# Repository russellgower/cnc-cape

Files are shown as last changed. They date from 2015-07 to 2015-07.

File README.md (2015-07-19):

CNC Cape for the Beaglebone Black.

<br />This work is licensed under a <a rel="license" href="http://creativecommons.org/licenses/by-sa/4.0/">Creative Commons Attribution-ShareAlike 4.0 International License</a>.

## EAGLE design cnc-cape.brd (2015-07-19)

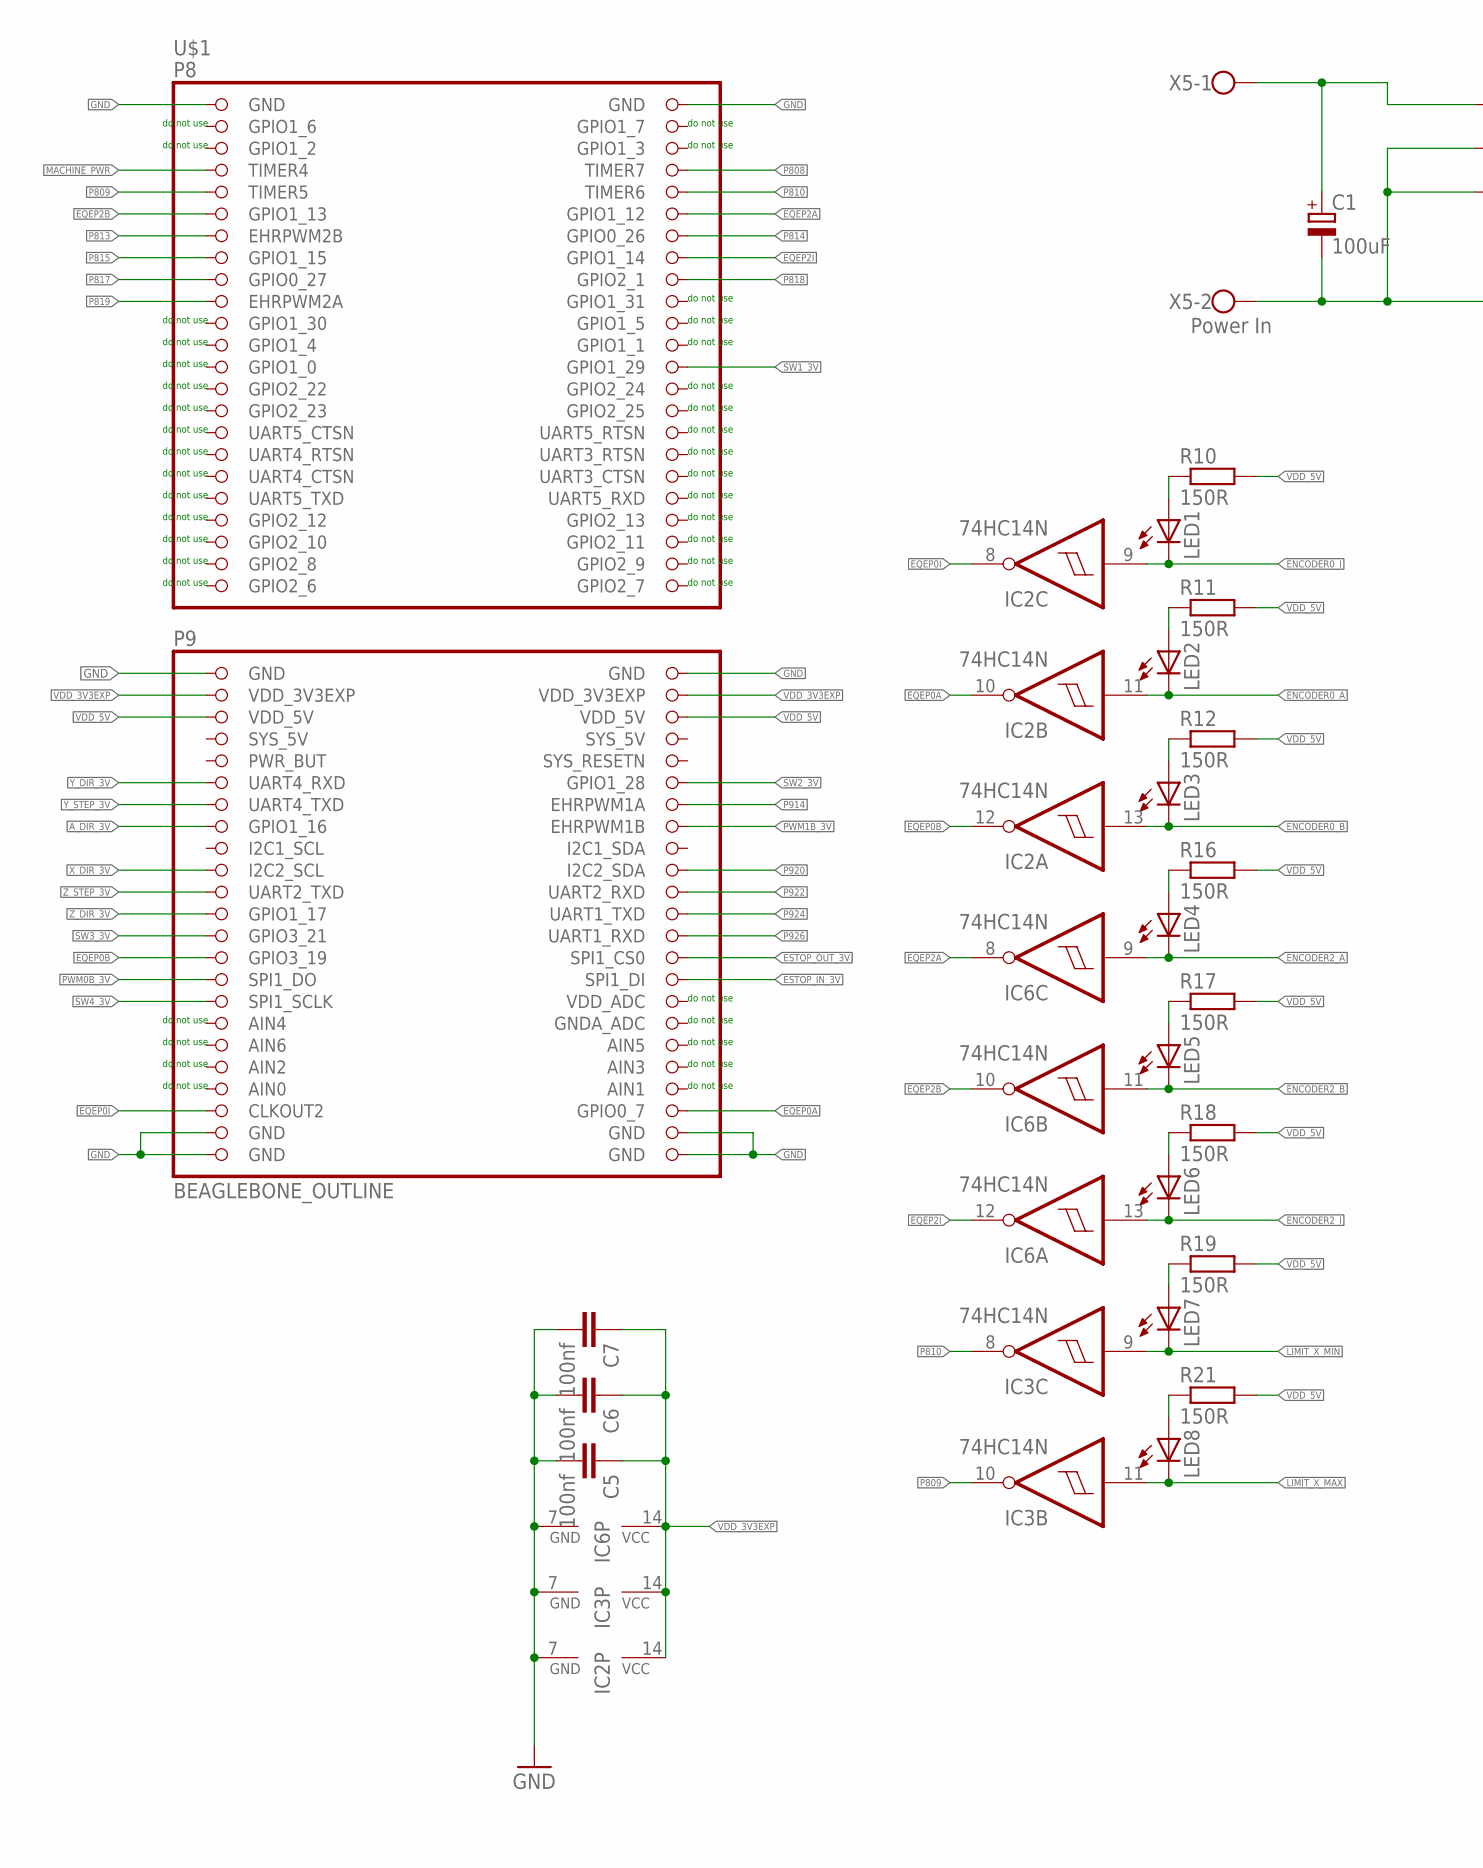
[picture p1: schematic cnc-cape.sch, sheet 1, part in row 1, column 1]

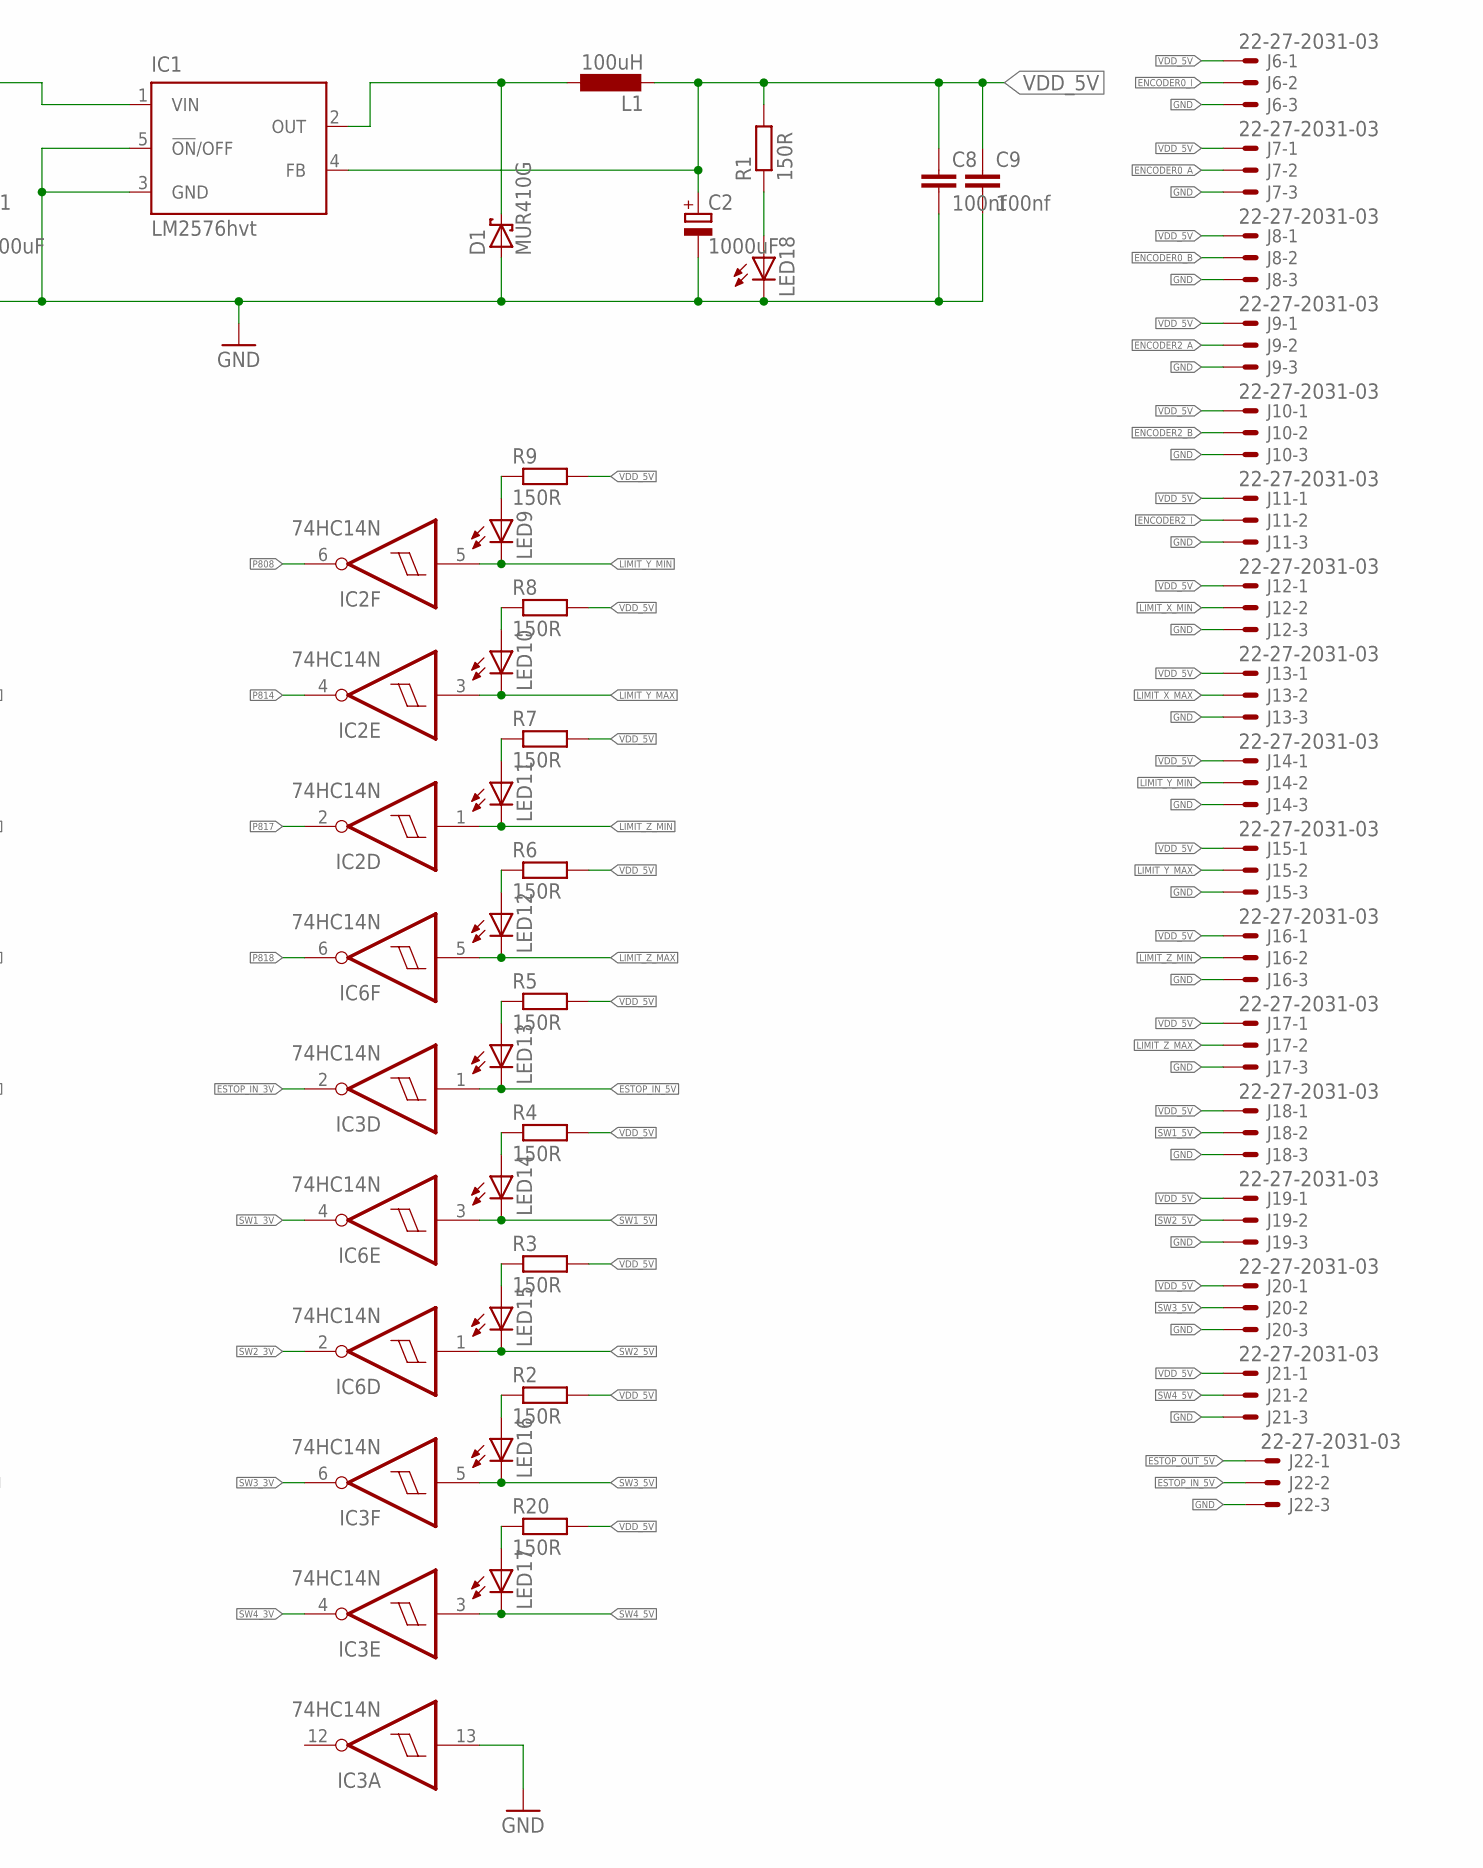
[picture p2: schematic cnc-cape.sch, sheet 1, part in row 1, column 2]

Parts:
C1: 100uF; E5-10,5; FARNELL 1281843
C2: 1000uF; E5-10,5; FARNELL 2346582
C5, C6, C7, C8, C9: 100nf; C050-024X044
D1: MUR410G; DO201T15; FARNELL 1459145
IC1: LM2576hvt; T05D
IC2, IC3, IC6: 74HC14N; DIL14; FARNELL 1739974
J6, J7, J8, J10, J11, J12, J13, J14, J15, J16, J17, J18, J19, J20, J21: 22-27-2031-03; 6410-03; FARNELL 9731156
J9, J22: 22-27-2031-03; 6410-03
L1: 100uH; KM-4.0; FARNELL 1209546
LED1, LED2, LED3, LED4, LED5, LED6, LED7, LED8, LED9, LED10, LED11, LED12, LED13, LED14, LED15, LED16, LED17, LED18: LED3MM; FARNELL 1581133
R1, R2, R3, R4, R5, R6, R7, R8, R9, R10, R11, R12, R16, R17, R18, R19, R20, R21: 150R; 0204/5; FARNELL 1700226
U$1: BEAGLEBONE_OUTLINE; BEAGLEBONE_SHIELD
X5: Power In; W237-102; FARNELL 3089034

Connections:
AIN0: U$1.85 (AIN0)
A_DIR_3V: U$1.61 (GPIO1_16); also elsewhere on the board
ENCODER0_A: IC2.11 (I), J7.2, LED2.K (C)
ENCODER0_B: IC2.13 (I), J8.2, LED3.K (C)
ENCODER0_I: IC2.9 (I), J6.2, LED1.K (C)
ENCODER2_A: IC6.9 (I), J9.2, LED4.K (C)
ENCODER2_B: IC6.11 (I), J10.2, LED5.K (C)
ENCODER2_I: IC6.13 (I), J11.2, LED6.K (C)
EQEP0A: IC2.10 (O), U$1.88 (GPIO0_7)
EQEP0B: IC2.12 (O), U$1.73 (GPIO3_19)
EQEP0I: IC2.8 (O), U$1.87 (CLKOUT2)
EQEP2A: IC6.8 (O), U$1.12 (GPIO1_12)
EQEP2B: IC6.10 (O), U$1.11 (GPIO1_13)
EQEP2I: IC6.12 (O), U$1.16 (GPIO1_14)
ESTOP_IN_3V: IC3.2 (O), U$1.76 (SPI1_DI)
ESTOP_IN_5V: IC3.1 (I), J22.2, LED13.K (C); also elsewhere on the board
ESTOP_OUT_3V: U$1.74 (SPI1_CS0); also elsewhere on the board
ESTOP_OUT_5V: J22.1; also elsewhere on the board
GND: C1.-, C2.-, C5.2, C6.2, C7.2, C8.2, C9.2, D1.A, IC1.3 (GND), IC1.5 (!ON!/OFF), IC2.7 (GND), IC3.7 (GND), IC3.13 (I), IC6.7 (GND), J6.3, J7.3, J8.3, J9.3, J10.3, J11.3, J12.3, J13.3, J14.3, J15.3, J16.3, J17.3, J18.3, J19.3, J20.3, J21.3, J22.3, LED18.K (C), U$1.1 (GND), U$1.2 (GND), U$1.47 (GND), U$1.48 (GND), U$1.89 (GND), U$1.90 (GND), U$1.91 (GND), U$1.92 (GND), X5.2; also elsewhere on the board
LIMIT_X_MAX: IC3.11 (I), J13.2, LED8.K (C)
LIMIT_X_MIN: IC3.9 (I), J12.2, LED7.K (C)
LIMIT_Y_MAX: IC2.3 (I), J15.2, LED10.K (C)
LIMIT_Y_MIN: IC2.5 (I), J14.2, LED9.K (C)
LIMIT_Z_MAX: IC6.5 (I), J17.2, LED12.K (C)
LIMIT_Z_MIN: IC2.1 (I), J16.2, LED11.K (C)
MACHINE_PWR: U$1.7 (TIMER4); also elsewhere on the board
unnamed: LED8.A, R21.1
unnamed: LED7.A, R19.1
unnamed: D1.C, IC1.2 (OUT), L1.P$1 (1)
unnamed: LED6.A, R18.1
unnamed: LED5.A, R17.1
unnamed: LED4.A, R16.1
unnamed: LED16.A, R2.1
unnamed: LED15.A, R3.1
unnamed: LED14.A, R4.1
unnamed: LED13.A, R5.1
unnamed: LED12.A, R6.1
unnamed: LED3.A, R12.1
unnamed: LED2.A, R11.1
unnamed: LED1.A, R10.1
unnamed: LED9.A, R9.1
unnamed: LED10.A, R8.1
unnamed: LED11.A, R7.1
unnamed: LED17.A, R20.1
unnamed: LED18.A, R1.1
P808: IC2.6 (O), U$1.8 (TIMER7)
P809: IC3.10 (O), U$1.9 (TIMER5)
P810: IC3.8 (O), U$1.10 (TIMER6)
P813: U$1.13 (EHRPWM2B); also elsewhere on the board
P814: IC2.4 (O), U$1.14 (GPIO0_26)
P815: U$1.15 (GPIO1_15); also elsewhere on the board
P817: IC2.2 (O), U$1.17 (GPIO0_27)
P818: IC6.6 (O), U$1.18 (GPIO2_1)
P819: U$1.19 (EHRPWM2A); also elsewhere on the board
P914: U$1.60 (EHRPWM1A); also elsewhere on the board
P920: U$1.66 (I2C2_SDA); also elsewhere on the board
P922: U$1.68 (UART2_RXD); also elsewhere on the board
P924: U$1.70 (UART1_TXD); also elsewhere on the board
P926: U$1.72 (UART1_RXD); also elsewhere on the board
PWM0B_3V: U$1.75 (SPI1_DO); also elsewhere on the board
PWM1B_3V: U$1.62 (EHRPWM1B); also elsewhere on the board
SW1_3V: IC6.4 (O), U$1.26 (GPIO1_29)
SW1_5V: IC6.3 (I), J18.2, LED14.K (C)
SW2_3V: IC6.2 (O), U$1.58 (GPIO1_28)
SW2_5V: IC6.1 (I), J19.2, LED15.K (C)
SW3_3V: IC3.6 (O), U$1.71 (GPIO3_21)
SW3_5V: IC3.5 (I), J20.2, LED16.K (C)
SW4_3V: IC3.4 (O), U$1.77 (SPI1_SCLK)
SW4_5V: IC3.3 (I), J21.2, LED17.K (C)
SYS_5V: U$1.53 (SYS_5V)
VCC: C1.+, IC1.1 (VIN), X5.1
VDD_3V3EXP: C5.1, C6.1, C7.1, IC2.14 (VCC), IC3.14 (VCC), IC6.14 (VCC), U$1.49 (VDD_3V3EXP), U$1.50 (VDD_3V3EXP)
VDD_5V: C2.+, C8.1, C9.1, IC1.4 (FB), J6.1, J7.1, J8.1, J9.1, J10.1, J11.1, J12.1, J13.1, J14.1, J15.1, J16.1, J17.1, J18.1, J19.1, J20.1, J21.1, L1.P$2 (2), R1.2, R2.2, R3.2, R4.2, R5.2, R6.2, R7.2, R8.2, R9.2, R10.2, R11.2, R12.2, R16.2, R17.2, R18.2, R19.2, R20.2, R21.2, U$1.51 (VDD_5V), U$1.52 (VDD_5V); also elsewhere on the board
X_DIR_3V: U$1.65 (I2C2_SCL); also elsewhere on the board
Y_DIR_3V: U$1.57 (UART4_RXD); also elsewhere on the board
Y_STEP_3V: U$1.59 (UART4_TXD); also elsewhere on the board
Z_DIR_3V: U$1.69 (GPIO1_17); also elsewhere on the board
Z_STEP_3V: U$1.67 (UART2_TXD); also elsewhere on the board

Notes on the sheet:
do not use

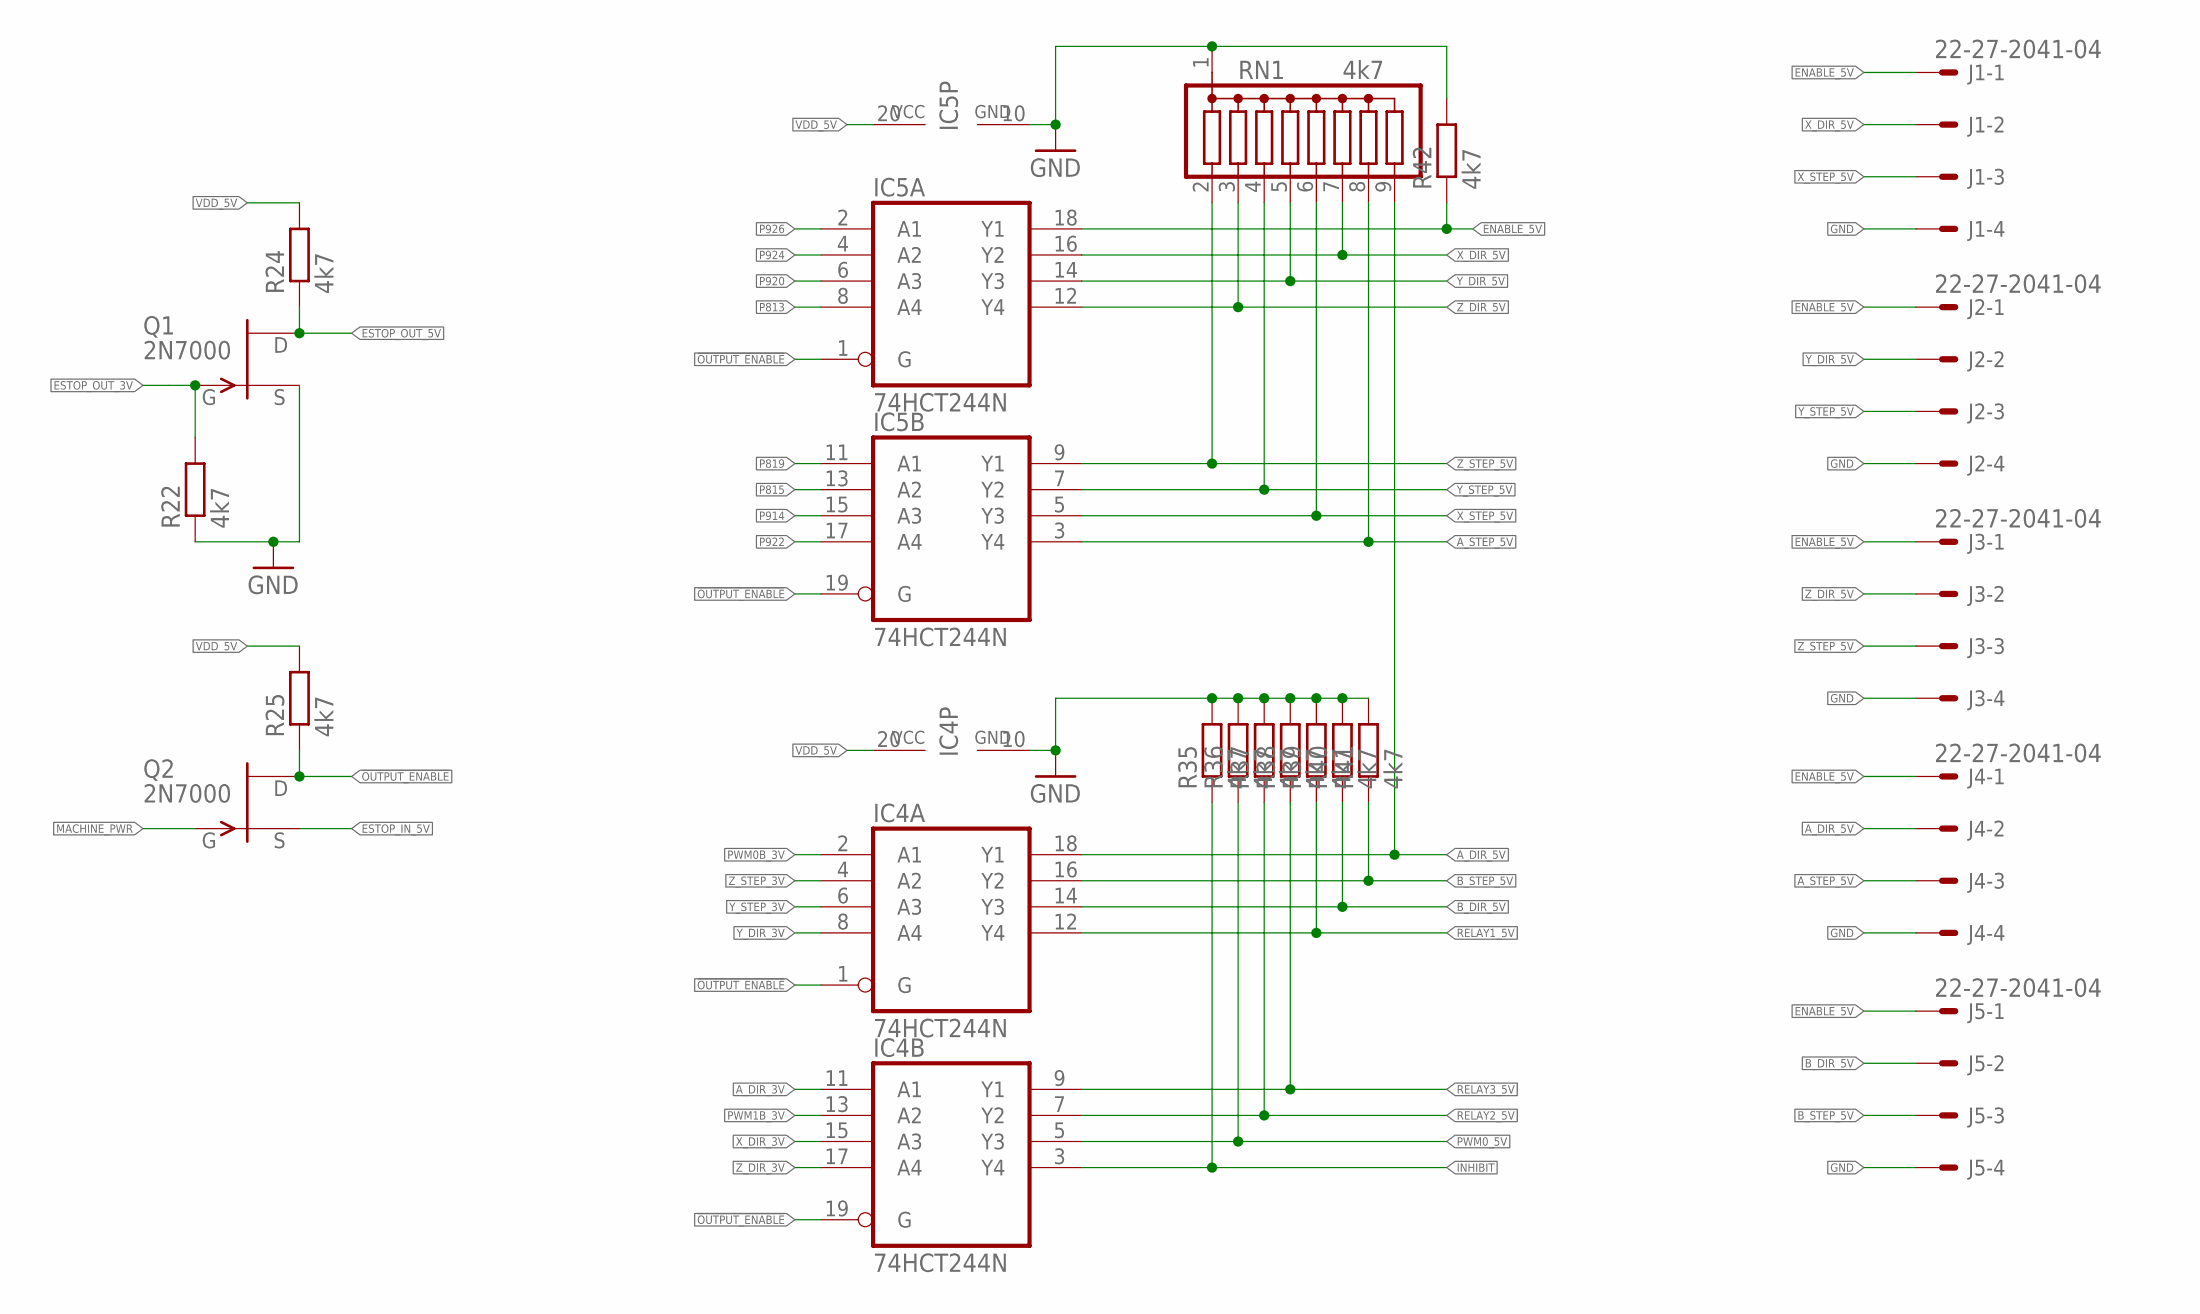
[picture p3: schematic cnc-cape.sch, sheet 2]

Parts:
IC4, IC5: 74HCT244N; DIL20; FARNELL 382267
J1, J2, J3, J4, J5: 22-27-2041-04; 6410-04; FARNELL 9731164
Q1, Q2: 2N7000; TO92; FARNELL 9845178
R22, R24, R25: 4k7; 0204/5; FARNELL 1700245
R35, R36, R37, R38, R39, R40, R41, R42: 4k7; 0204/5
RN1: 4k7; SIL9; FARNELL 9357025

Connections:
!OUTPUT_ENABLE!: IC4.1 (G), IC4.19 (G), IC5.1 (G), IC5.19 (G), Q2.1 (D), R25.1
A_DIR_3V: IC4.11 (A1); also elsewhere on the board
A_DIR_5V: IC4.18 (Y1), J4.2, RN1.9
A_STEP_5V: IC5.3 (Y4), J4.3, RN1.8
B_DIR_5V: IC4.14 (Y3), J5.2, R40.1
B_STEP_5V: IC4.16 (Y2), J5.3, R41.1
ENABLE_5V: IC5.18 (Y1), J1.1, J2.1, J3.1, J4.1, J5.1, R42.1
ESTOP_IN_5V: Q2.3 (S); also elsewhere on the board
ESTOP_OUT_3V: Q1.2 (G), R22.2; also elsewhere on the board
ESTOP_OUT_5V: Q1.1 (D), R24.1; also elsewhere on the board
GND: IC4.10 (GND), IC5.10 (GND), J1.4, J2.4, J3.4, J4.4, J5.4, Q1.3 (S), R22.1, R35.2, R36.2, R37.2, R38.2, R39.2, R40.2, R41.2, R42.2, RN1.1; also elsewhere on the board
INHIBIT: IC4.3 (Y4), R35.1; also elsewhere on the board
MACHINE_PWR: Q2.2 (G); also elsewhere on the board
P813: IC5.8 (A4); also elsewhere on the board
P815: IC5.13 (A2); also elsewhere on the board
P819: IC5.11 (A1); also elsewhere on the board
P914: IC5.15 (A3); also elsewhere on the board
P920: IC5.6 (A3); also elsewhere on the board
P922: IC5.17 (A4); also elsewhere on the board
P924: IC5.4 (A2); also elsewhere on the board
P926: IC5.2 (A1); also elsewhere on the board
PWM0B_3V: IC4.2 (A1); also elsewhere on the board
PWM0_5V: IC4.5 (Y3), R36.1; also elsewhere on the board
PWM1B_3V: IC4.13 (A2); also elsewhere on the board
RELAY1_5V: IC4.12 (Y4), R39.1; also elsewhere on the board
RELAY2_5V: IC4.7 (Y2), R37.1; also elsewhere on the board
RELAY3_5V: IC4.9 (Y1), R38.1; also elsewhere on the board
VDD_5V: IC4.20 (VCC), IC5.20 (VCC), R24.2, R25.2; also elsewhere on the board
X_DIR_3V: IC4.15 (A3); also elsewhere on the board
X_DIR_5V: IC5.16 (Y2), J1.2, RN1.7
X_STEP_5V: IC5.5 (Y3), J1.3, RN1.6
Y_DIR_3V: IC4.8 (A4); also elsewhere on the board
Y_DIR_5V: IC5.14 (Y3), J2.2, RN1.5
Y_STEP_3V: IC4.6 (A3); also elsewhere on the board
Y_STEP_5V: IC5.7 (Y2), J2.3, RN1.4
Z_DIR_3V: IC4.17 (A4); also elsewhere on the board
Z_DIR_5V: IC5.12 (Y4), J3.2, RN1.3
Z_STEP_3V: IC4.4 (A2); also elsewhere on the board
Z_STEP_5V: IC5.9 (Y1), J3.3, RN1.2

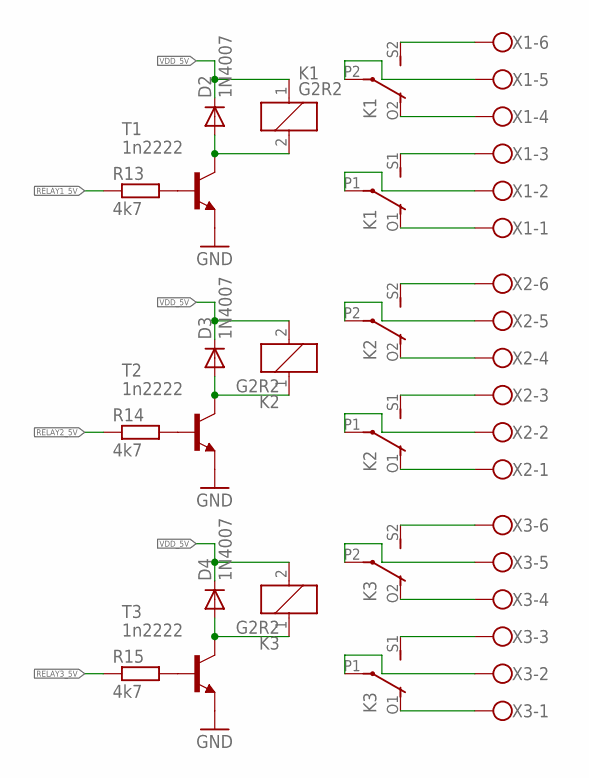
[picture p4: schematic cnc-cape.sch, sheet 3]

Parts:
D2, D3, D4: 1N4007; DO41-10; FARNELL 9565051
K1, K2, K3: G2R2; FARNELL 1703716
R13, R14, R15: 4k7; 0204/5; FARNELL 1700245
T1, T2, T3: 1n2222; TO92; FARNELL 1611371
X1, X2, X3: W237-6; FARNELL 3089071

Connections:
GND: T1.1 (E), T2.1 (E), T3.1 (E); also elsewhere on the board
unnamed: R13.2, T1.2 (B)
unnamed: D2.A, K1.2, T1.3 (C)
unnamed: K1.S2 (S), X1.6
unnamed: K1.O2 (O), X1.4
unnamed: K1.P2, X1.5
unnamed: K1.S1 (S), X1.3
unnamed: K1.P1, X1.2
unnamed: K1.O1 (O), X1.1
unnamed: R14.2, T2.2 (B)
unnamed: D3.A, K2.1, T2.3 (C)
unnamed: K2.S2 (S), X2.6
unnamed: K2.O2 (O), X2.4
unnamed: K2.P2, X2.5
unnamed: K2.S1 (S), X2.3
unnamed: K2.P1, X2.2
unnamed: K2.O1 (O), X2.1
unnamed: R15.2, T3.2 (B)
unnamed: D4.A, K3.1, T3.3 (C)
unnamed: K3.S2 (S), X3.6
unnamed: K3.O2 (O), X3.4
unnamed: K3.P2, X3.5
unnamed: K3.S1 (S), X3.3
unnamed: K3.P1, X3.2
unnamed: K3.O1 (O), X3.1
RELAY1_5V: R13.1; also elsewhere on the board
RELAY2_5V: R14.1; also elsewhere on the board
RELAY3_5V: R15.1; also elsewhere on the board
VDD_5V: D2.C, D3.C, D4.C, K1.1, K2.2, K3.2; also elsewhere on the board

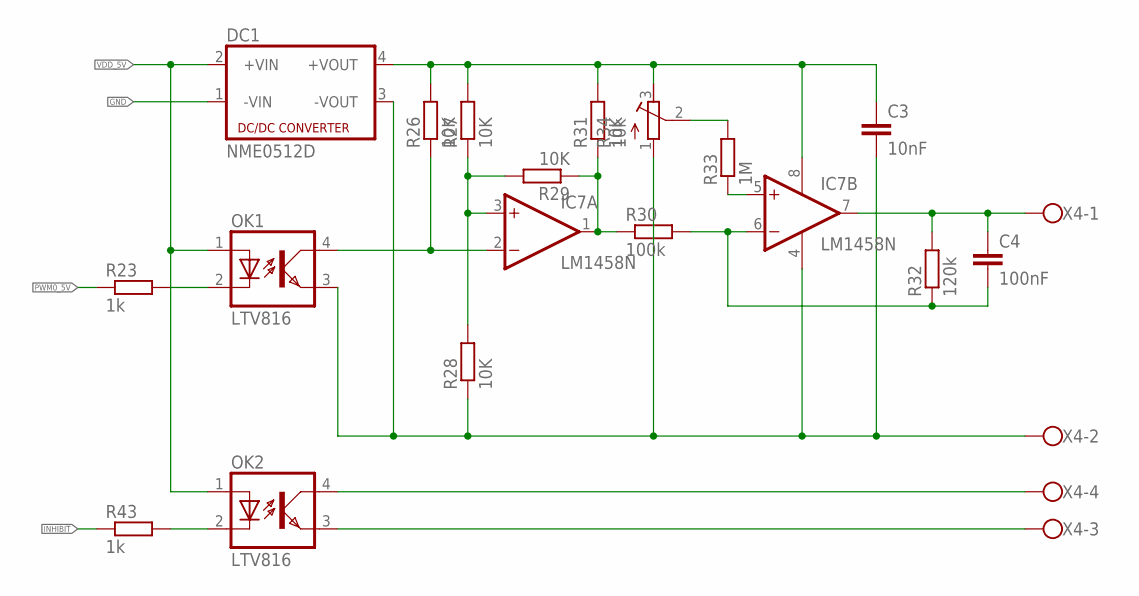
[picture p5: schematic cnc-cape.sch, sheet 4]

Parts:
C3: 10nF; C050-024X044
C4: 100nF; C050-024X044
DC1: NME0512D; NME; FARNELL 1021457
IC7: LM1458N; DIL08
OK1, OK2: LTV816; DIL04
R23, R43: 1k; 0204/5
R26, R27, R28, R29, R31: 10K; 0204/5; FARNELL 1700251
R30: 100k; 0204/5
R32: 120k; 0204/5
R33: 1M; 0204/5
R34: 10k; RTRIM64P
X4: W237-4

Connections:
GND: DC1.1 (-VIN); also elsewhere on the board
INHIBIT: R43.1; also elsewhere on the board
unnamed: C3.1, DC1.4 (+VOUT), IC7.8 (V+), R26.2, R27.2, R31.2, R34.3 (E)
unnamed: OK1.2 (C), R23.2
unnamed: OK2.4 (COL), X4.4
unnamed: IC7.2 (-IN), OK1.4 (COL), R26.1
unnamed: IC7.3 (+IN), R27.1, R28.2, R29.2
unnamed: IC7.1 (OUT), R29.1, R30.1, R31.1
unnamed: C4.2, IC7.6 (-IN), R30.2, R32.1
unnamed: OK2.3 (EMIT), X4.3
unnamed: OK2.2 (C), R43.2
unnamed: IC7.5 (+IN), R33.1
unnamed: R33.2, R34.2 (S)
PWM0_5V: R23.1; also elsewhere on the board
SPINDLE+: C4.1, IC7.7 (OUT), R32.2, X4.1
SPINDLE-: C3.2, DC1.3 (-VOUT), IC7.4 (V-), OK1.3 (EMIT), R28.1, R34.1 (A), X4.2
VDD_5V: DC1.2 (+VIN), OK1.1 (A), OK2.1 (A); also elsewhere on the board

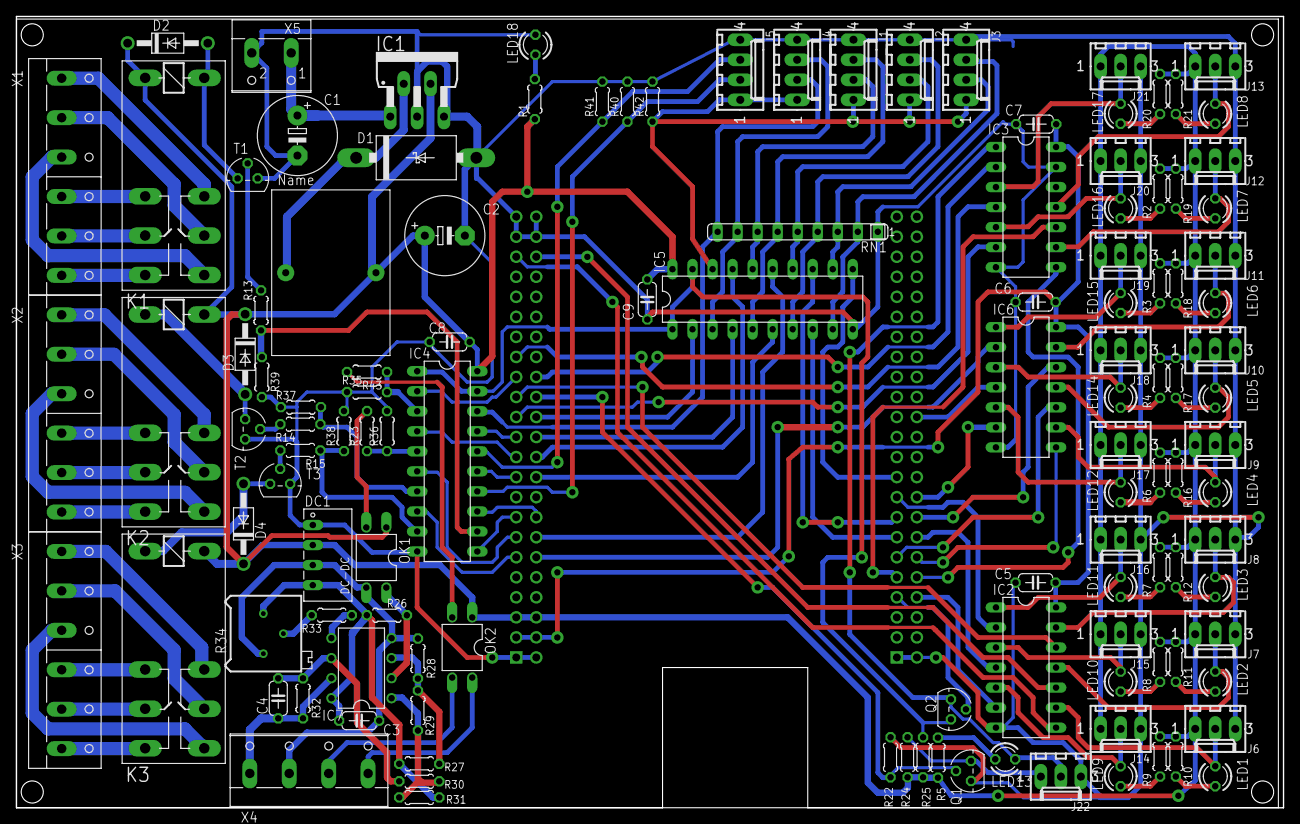
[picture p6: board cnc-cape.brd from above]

Board: 2 copper layers, 160.7 x 100.3 mm, 122 parts (1 on the bottom side), 130 nets.

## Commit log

2015-03-25 Rearraged layout to reduce via count
    [cnc-cape.brd, cnc-cape.sch]
2015-04-09 Fixed pwm polarity
    [cnc-cape.brd, cnc-cape.sch]
2015-04-09 Added opto coupled inhibit out put, to disable spindle driver
    [cnc-cape.brd, cnc-cape.sch]
2015-07-19 fixed some net names
    [cnc-cape.brd, cnc-cape.sch]
2015-07-19 added license
    [cnc-cape.csv]
